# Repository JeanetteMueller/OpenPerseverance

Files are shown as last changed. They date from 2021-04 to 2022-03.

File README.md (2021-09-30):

# OpenPerseverance
This is a large Project about building your own Perseverance Mars Rover. 
3D printed and remote controlled. 

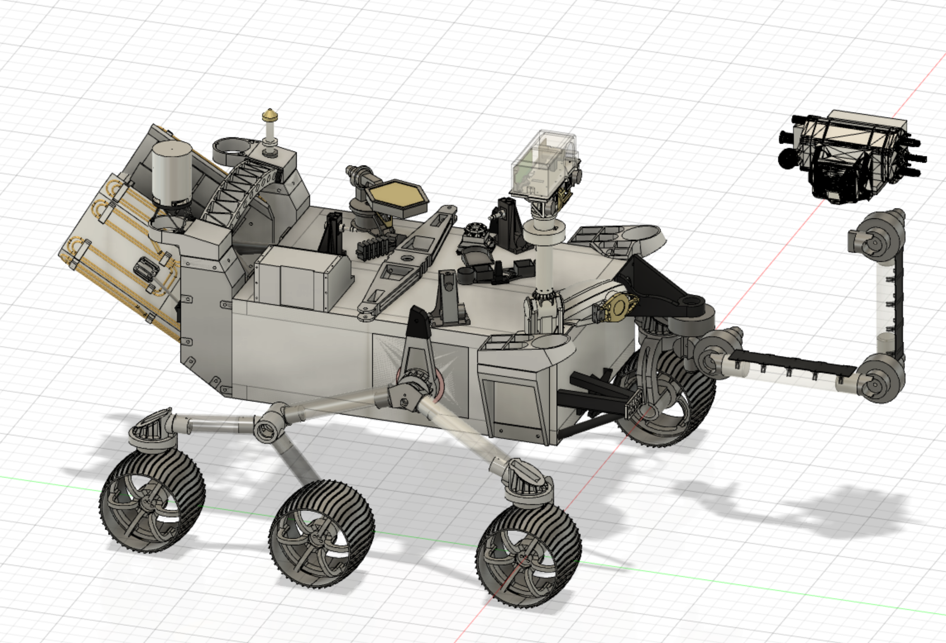
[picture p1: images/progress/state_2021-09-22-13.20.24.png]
CAD of Percy, 22. September 2021


Image of Percy with her Maker, 8. September 2021

Image of Percy, 8. September 2021

## Build your own rover
Under the Directory "stl" you find all needed printable parts for your rover. I will update and add new files while development.

### MainBody
* BridgeBase 
* DifferentialBodyMount
* DifferentialBlocker
* FrontBodyCamera
* HighGainAntenna
* LowGainAntenna
* SampleCollector
* ShellConnector
* ShellToProfileConnector
* SkyCraneConnector
* Sundial
* TopBox
* UHF

### RockerBogie
* WheelHolderCenter
* WheelHolder
* Tire
* Wheel Rim
* RodConnectorFront
* ServoConnector
* DifferentialMount
* RodConnectorBack
* DifferentialArm
* DifferentialArmHead
* CenterRodMount
* CenterRodMountCover
* BoogieCenterInternal
* BearingCenter
* BoogieCenterExternal
* BalanceArmConnector
* BalanceArmCenter
* BalanceArm

### Tower
(to be added)

### HeatExchanger
* Wall
* Holder
* Heatpipes
	
### Arm
(to be added)

## Remote Control
I designed everything to controll the rover with a PS4 Gamepad, connected to an iPhone. The iPhone is the brain of everything. It translate the gamepad signals to json code the rover need to move. The iPhone also shows the camera images of all installed cameras. 

## Rover brain
The Rover main Functions run on a Raspberry Pi 3b with 3 MotorController Boards and two Servo Shield. 
Inside of the Camera Tower you need a Raspberry Pi Zero W to control the Head mounted Camera and the Lights around the eyelid. 
All Programming is done in python (i am new with python so this would be a great opportunity to make this project better)

## Instructions

### Main Body
* 20x20 Alloy profile B-Type Nut 6
	4x 30cm
	5x 40cm
* 8x Angle 20 x 40 Nut 6 Bosch grid with fastening
* 50x Hammer Nut 6 M4
* Ball Bearings
	4x 35 x 47 x 7 mm   
	8x 8 x 22 x 7mm
* Alloy Rod 25 mm x 2 mm (inner Diameter 21mm)
	* 4x 150mm
	* 2x 100mm
	* 2x 120mm
* 4x JX Servo 1181MG
* 2x Servo MG90s
* Raspberry Pi 3b (or newer)
* Raspberry Pi Zero W
* Camera Longruner for Raspberry Pi
* ESP32 with Cam

### UHF Antenna
Needs 6 Carbon Rods: 40mm on front, 44mm on center and 41mm on the back. Two of each with a diameter of 2mm.

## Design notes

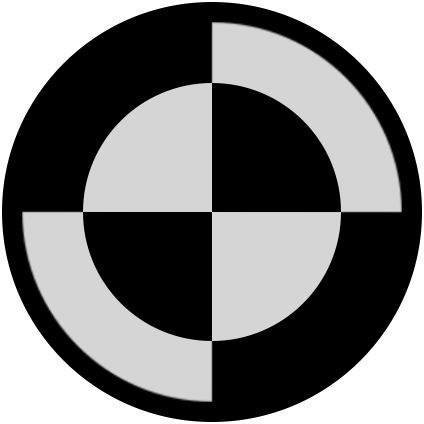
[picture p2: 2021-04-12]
images/decals/RoverMarker.png

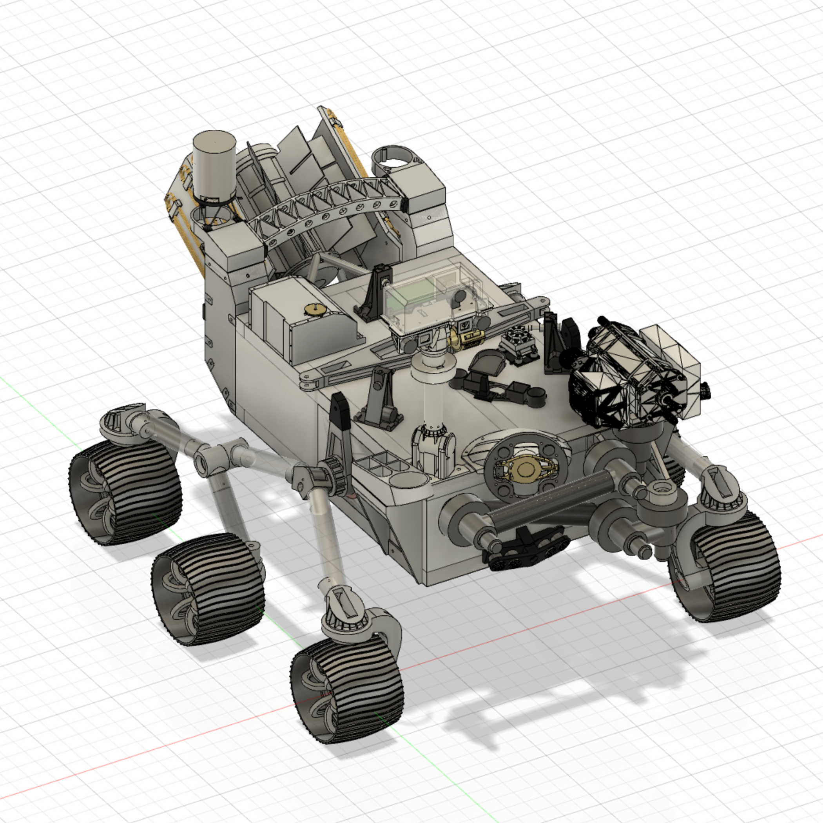
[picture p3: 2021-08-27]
images/progress/state_2021-08-19_17.00.37.png

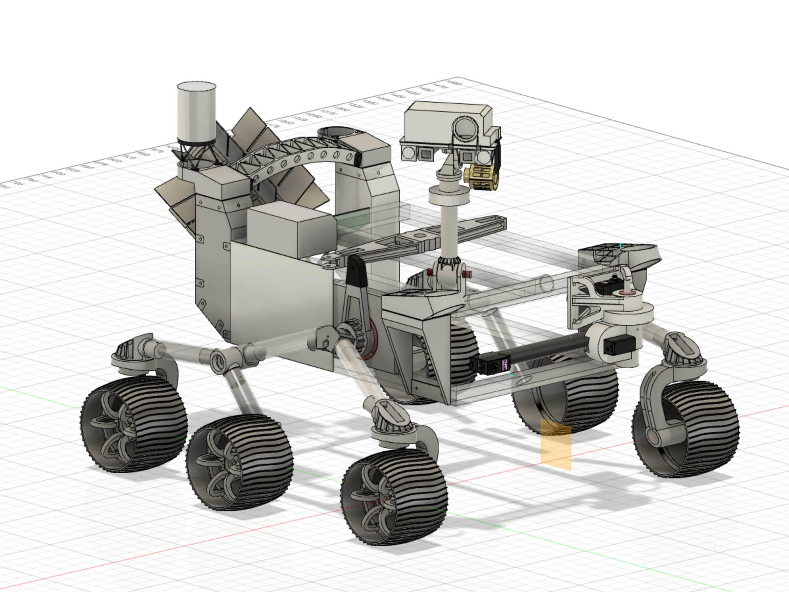
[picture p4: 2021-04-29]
images/progress/state_2021-04-29_10.36.57.png

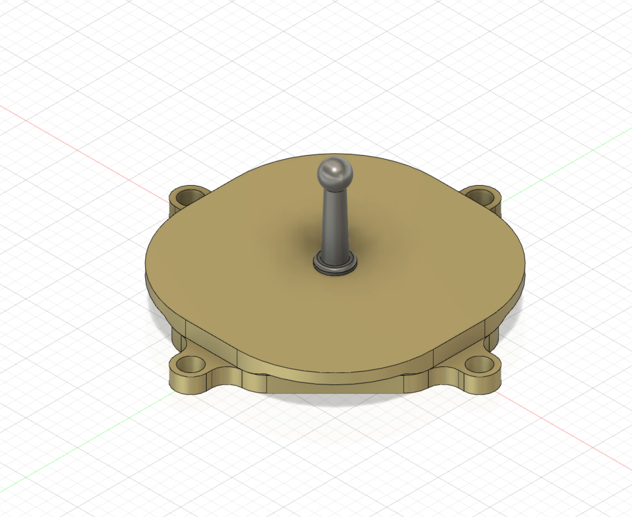
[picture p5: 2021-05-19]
stl/MainBody/Sundial/Sundial.png

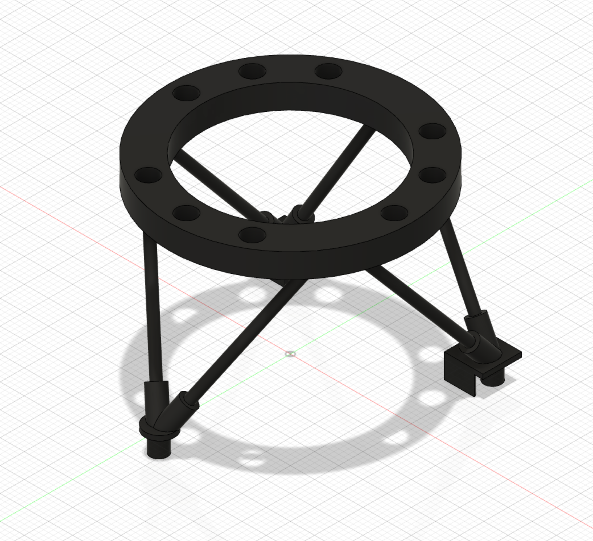
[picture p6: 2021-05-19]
stl/MainBody/UHF/UHF-Mount.png

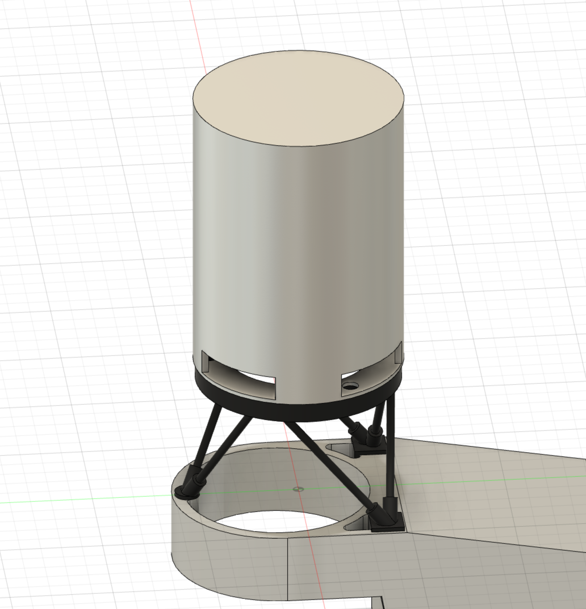
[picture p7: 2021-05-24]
stl/MainBody/UHF/UHF.png

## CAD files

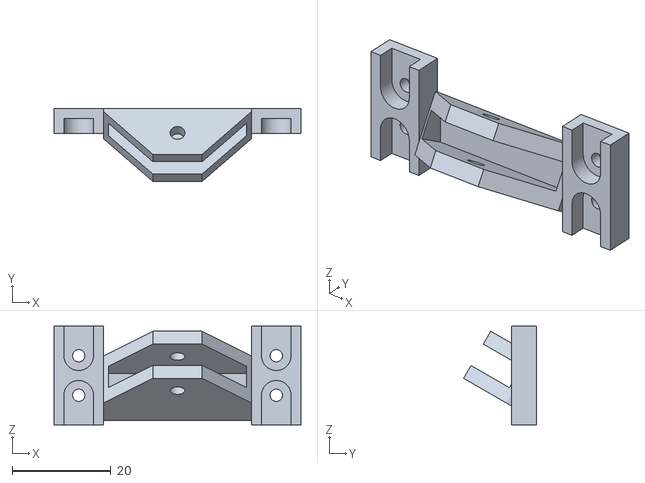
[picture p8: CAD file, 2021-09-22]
stl/HeatExchanger_Left/Holder/HeatExchangerHolder MainbodyMountPoint.stl
50.0 x 14.8 x 20.0

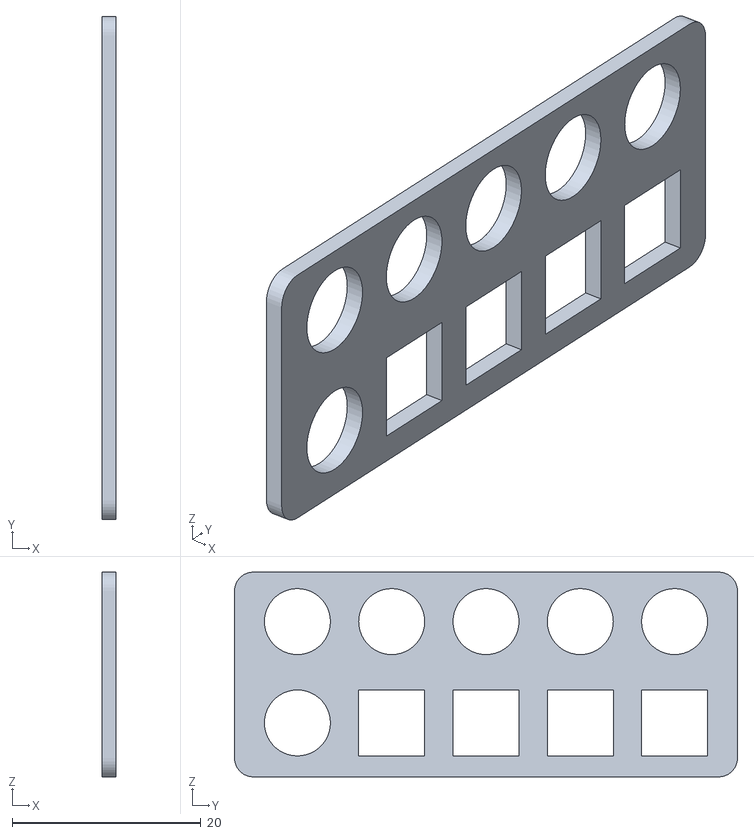
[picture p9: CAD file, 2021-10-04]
stl/Arm/ArmStandReferencesLid.stl
1.50 x 53.3 x 21.7

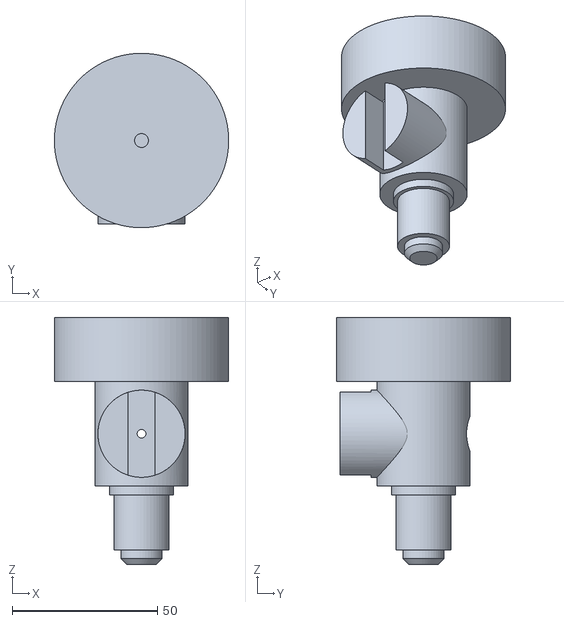
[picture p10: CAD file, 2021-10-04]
stl/Arm/Hand/HandActuator.stl
60.0 x 60.0 x 85.0

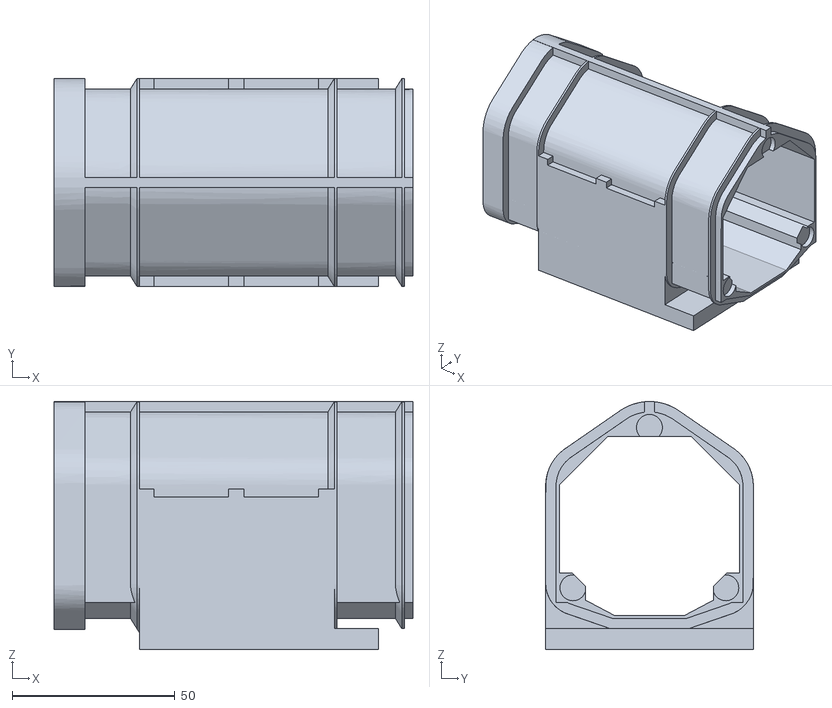
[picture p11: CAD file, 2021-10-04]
stl/Arm/Instruments/InstrumentsCenter.stl
110.4 x 63.9 x 76.3

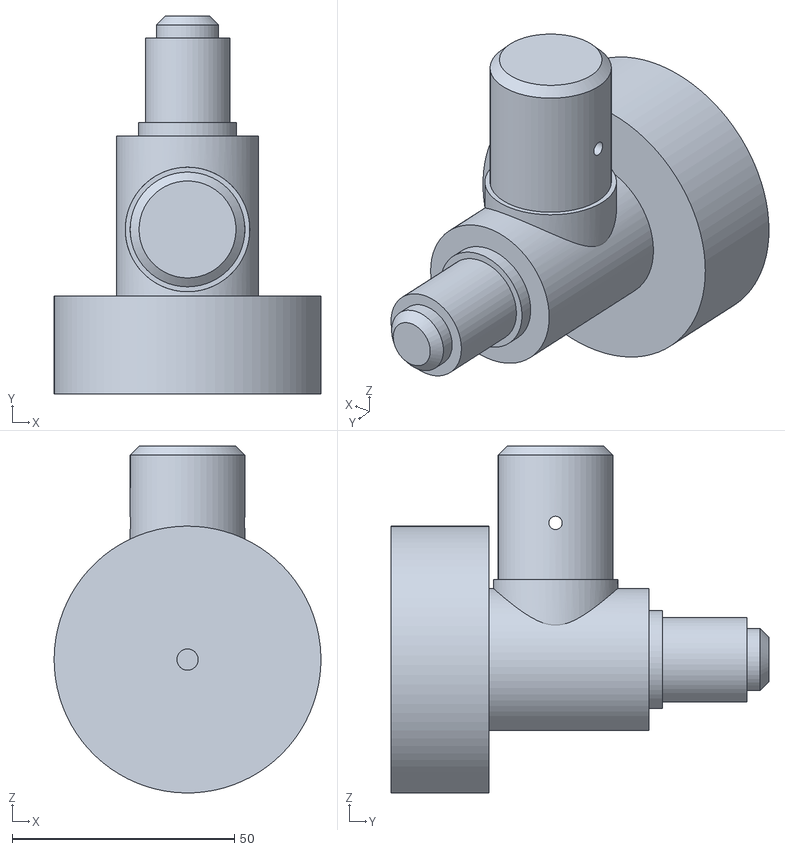
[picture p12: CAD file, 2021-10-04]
stl/Arm/LowerArm/LowerArmAktuator1.stl
60.0 x 85.0 x 78.0

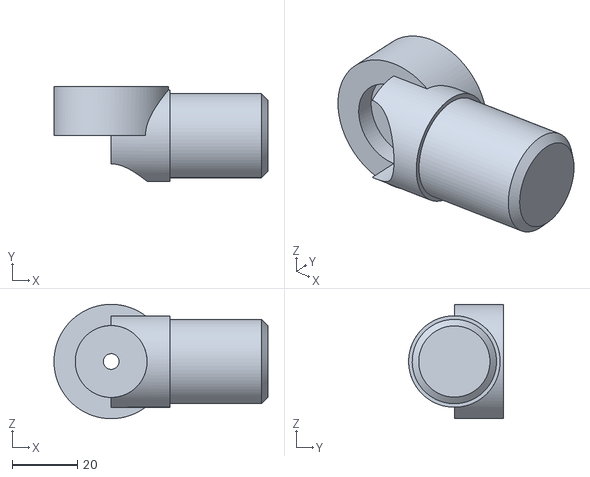
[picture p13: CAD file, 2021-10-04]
stl/Arm/UpperArm/UpperArmRodConnector1.stl
65.5 x 29.0 x 35.0

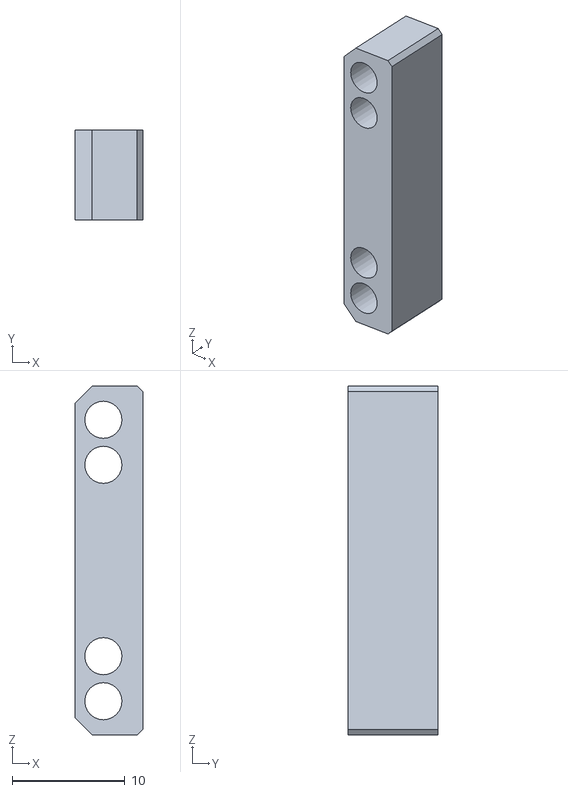
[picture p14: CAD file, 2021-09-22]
stl/HeatExchanger_Left/Heatpipes/HeatExchanger Holder 7.stl
6.00 x 8.00 x 31.0

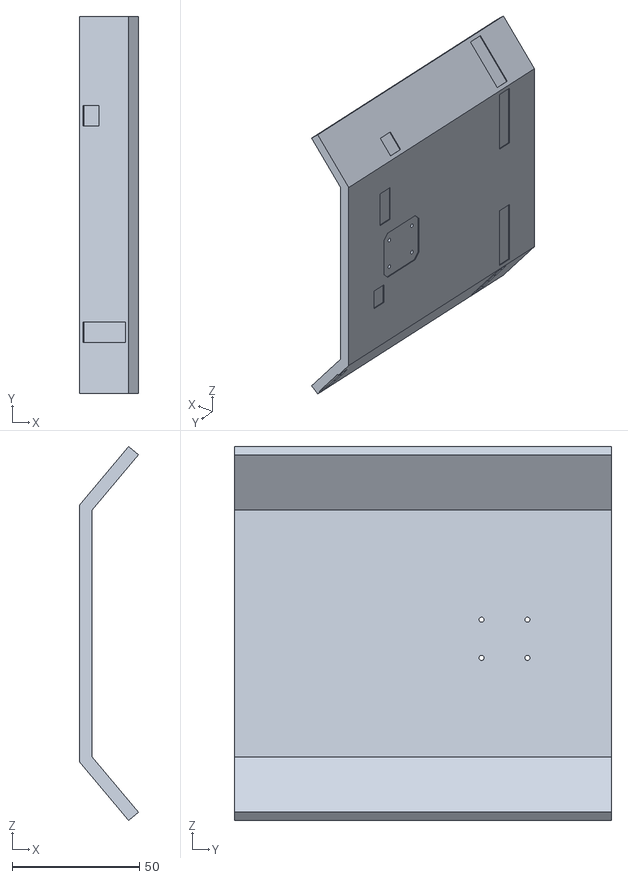
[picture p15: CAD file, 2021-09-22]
stl/HeatExchanger_Left/Wall/HeatExchanger Wall_Left_2.stl
23.2 x 148.0 x 146.8

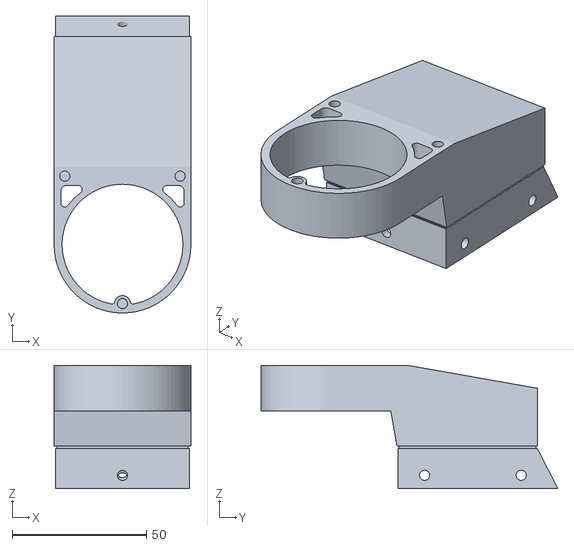
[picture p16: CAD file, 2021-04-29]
stl/MainBody/BridgeBase.stl
51.0 x 110.7 x 46.0

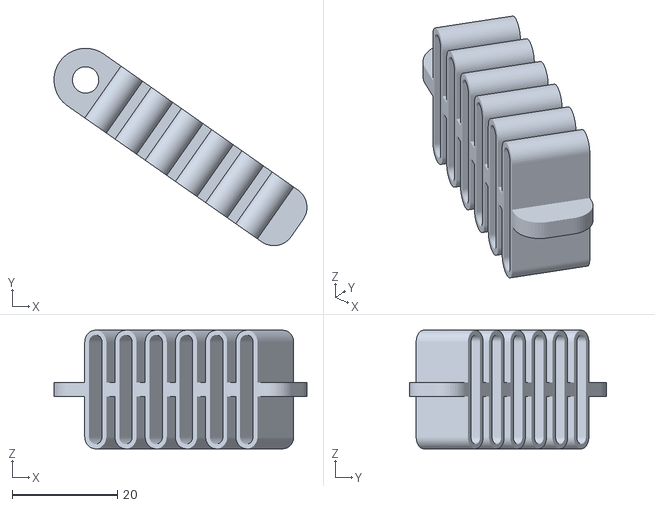
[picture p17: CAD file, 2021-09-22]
stl/MainBody/DifferentialBlocker/DifferentialBlocker Flex.stl
48.0 x 37.4 x 22.5

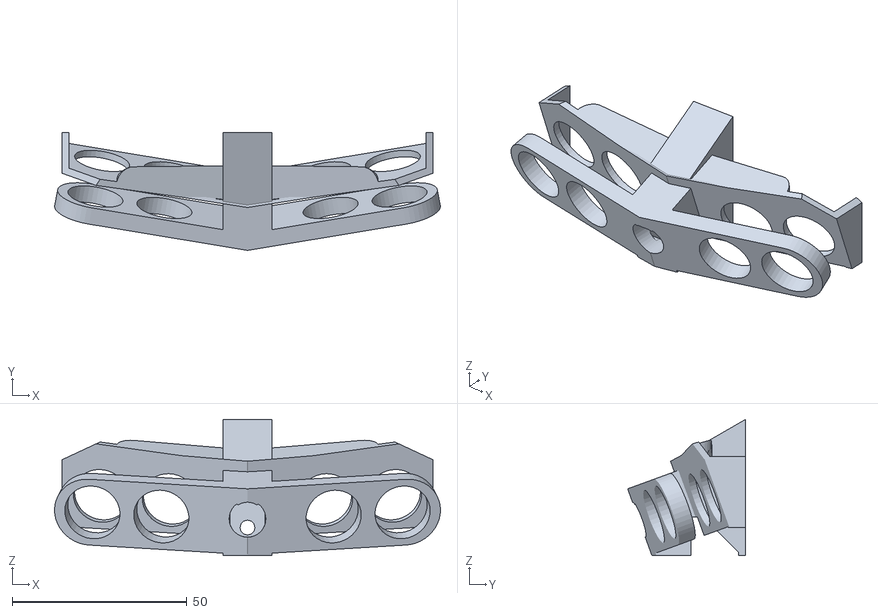
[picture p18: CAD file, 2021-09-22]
stl/MainBody/FrontBodyCamera/FrontBodyCameraHolder.stl
110.3 x 33.7 x 38.9

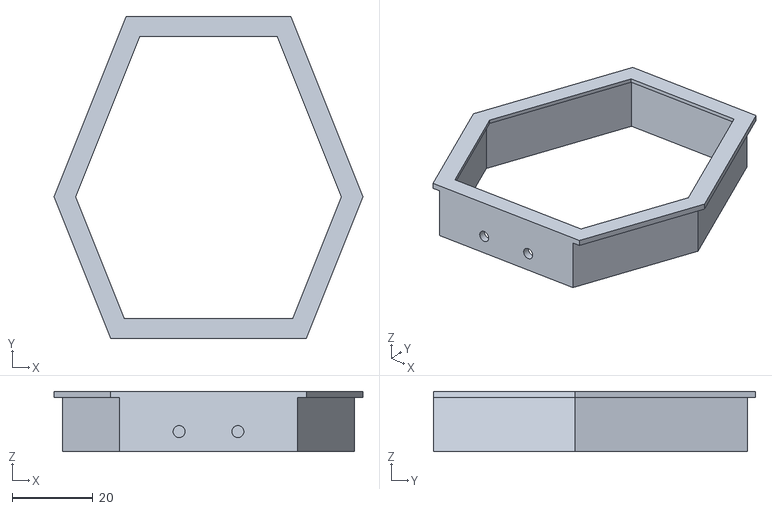
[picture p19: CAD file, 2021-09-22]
stl/MainBody/HighGainAntenna/HighGainAntenna RecieverCage.stl
76.8 x 80.0 x 15.0

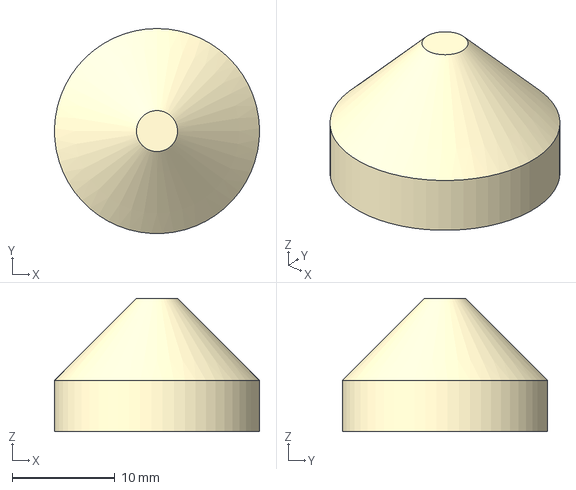
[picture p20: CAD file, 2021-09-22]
stl/MainBody/LowGainAntenna/LowGainAntenna Head.step
20.0 x 20.0 x 13.0 mm

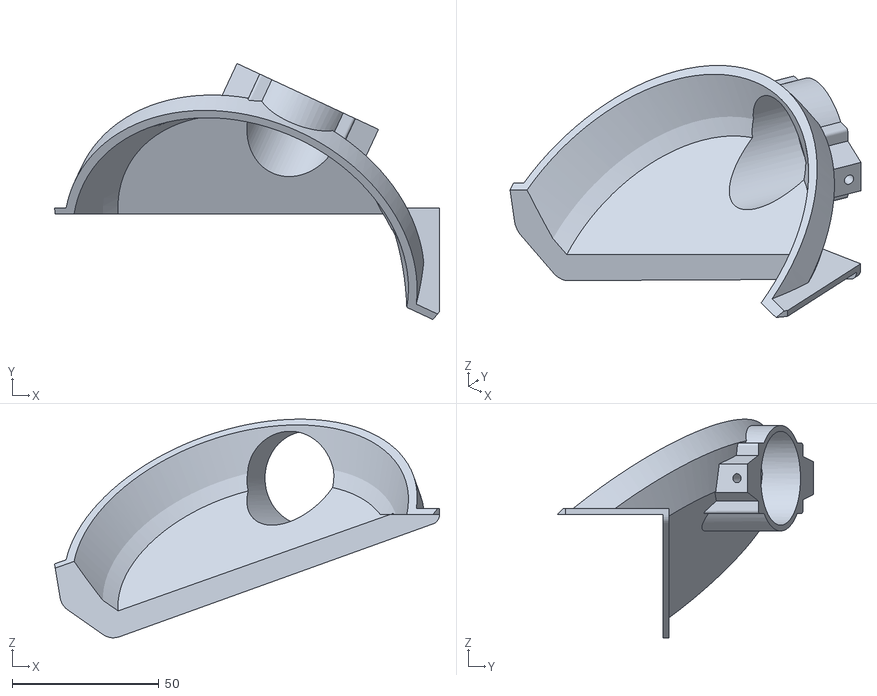
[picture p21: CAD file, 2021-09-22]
stl/MainBody/SampleCollector/CollectorBottom.stl
131.2 x 87.3 x 74.5

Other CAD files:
stl/MainBody/SkyCraneConnector/SkyCraneConnector CableCutter.stl
stl/MainBody/Sundial/SundialBase.stl
stl/MainBody/TopBox/TopBodyBox Back.stl
stl/MainBody/UHF/UHF-FootRight.stl
stl/Arm/ArmHolder.stl
stl/Arm/ArmStand.stl
stl/Arm/ArmStandReferencesMount.stl
stl/Arm/Hand/HandConnector.stl
stl/Arm/Instruments/InstrumentsBaseplate.stl
stl/Arm/Instruments/InstrumentsBaseplateConnector.stl
stl/Arm/Instruments/InstrumentsCamera.stl
stl/Arm/Instruments/InstrumentsCameraSensor.stl
stl/Arm/Instruments/InstrumentsDrill.stl
stl/Arm/Instruments/InstrumentsPixl.stl
stl/Arm/Instruments/InstrumentsSherlocWatsonBody.stl
stl/Arm/Instruments/InstrumentsSherlocWatsonSensor1.stl
stl/Arm/Instruments/InstrumentsSherlocWatsonSensor2.stl
stl/Arm/LowerArm/LowerArmAktuator2.stl
stl/Arm/NamePlate.stl
stl/Arm/NamePlateHolder.stl
stl/Arm/UpperArm/UpperArmAktuator2.stl
stl/Arm/UpperArm/UpperArmRodConnector2.stl
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

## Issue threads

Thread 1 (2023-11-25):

not enough detail

queenidog, 2023-11-25:
I don't see the detail (STL) around the connection between the drive motors and the wheel hub.  There are 3 screws holding the wheel on  but how is that connected to the motor shaft?   Where are the motors?

JeanetteMueller, 2023-11-27:
There is space for the motor in the "WheelHolder.stl". it should be a 27mm motor. There is space for the motor axle in the center. There are two additional holes to the left and right of this hole to securely fix the motor.

JeanetteMueller, 2023-11-27:
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

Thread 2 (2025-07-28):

Is the main body/frame structure missing?

Jstyund, 2025-07-28:
Hi,
I can’t find the main structural frame of the rover — like the chassis or base that holds everything together.
Is it missing, or just not included in the files? Or did I overlook it?

Thanks.

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

JeanetteMueller, 2025-07-28:
hi, these are just ABS plates i cuttet to the needed structure. it is not 3d printed.

JeanetteMueller, 2025-07-28:
the side plate goes up to the bridge, too.
i may have time later to take a photo and add measurements to it

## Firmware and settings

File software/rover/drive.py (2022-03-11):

#!/usr/bin/env python
from __future__ import division
from threading import Thread
import sys
import socket
import json
import time
from time import sleep
from Communication import Communication
from Communicator import Communicator

from adafruit_motorkit import MotorKit
import board

com = Communication("drive")

sock = com.getSocket()
sock.bind((com.ip, com.getPortForDrive()))

kit1 = MotorKit(address=0x62)
kit2 = MotorKit(address=0x61)

class DriveReactor(Thread):
    changed = 1
    timeout = 0
    motorLeft = 0
    motorLeftCenter = 0
    
    motorRight = 0
    motorRightCenter = 0
    
    def __init__(self):
        Thread.__init__(self)
        self.daemon = True
        self.start()

    def run(self):
        print("start run")
        while True:
            if self.timeout > 0:
                self.timeout = self.timeout - 1

            if self.timeout <= 0:
                self.motorLeft = 0
                self.motorLeftCenter = 0
                self.motorRight = 0
                self.motorRightCenter = 0
                print("-------------- FULL STOP -------------")

            kit1.motor1.throttle = self.motorLeft
            kit1.motor3.throttle = self.motorLeft
            kit1.motor2.throttle = self.motorLeftCenter
            kit2.motor1.throttle = self.motorRight
            kit2.motor3.throttle = self.motorRight
            kit2.motor2.throttle = self.motorRightCenter
            print("set new motor values " + str(self.timeout))
            sleep(0.02)
            
    def newTimeout(self):
        self.timeout = 10
        print("--------------------set new timeout ")
    def parseMessage(self,msg):
        jsonData = json.loads(msg)
        print("parse message for drive " + str(msg))
        
        if "drive" in jsonData:
            drive = jsonData["drive"]

            self.newTimeout()
            if "ml" in drive:
                if "mlc" in drive:
                    if "mr" in drive:
                        if "mrc" in drive:
                            self.motorLeft = drive["ml"]
                            self.motorLeftCenter = drive["mlc"]
                            self.motorRight = drive["mr"] * -1
                            self.motorRightCenter = drive["mrc"] * -1
                            

runner = DriveReactor()
Communicator(sock, runner)

while True:
    #print("main while loop")
    pass

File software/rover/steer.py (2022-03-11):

#!/usr/bin/env python
from __future__ import division

from threading import Thread
import sys
import socket
import json
import time
import math
from time import sleep

# from PCA9685 import PCA9685
from Adafruit_PCA9685 import PCA9685

from Communication import Communication
from Communicator import Communicator
from Helper import Helper

com = Communication("steer")

sock = com.getSocket()
sock.bind((com.ip, com.getPortForSteer()))

#### Servo
pwm = PCA9685(address=0x40)
servo_min = 150.0  # Min pulse length out of 4096
servo_max = 650.0  # Max pulse length out of 4096
pwm.set_pwm_freq(50)

class SteerReactor(Thread):
    helper = Helper()
    
    lastSteerChange = 0
    lastArmChange = 0
    
    steerFrontLeft  = 85
    steerFrontRight = 85
    steerBackLeft   = 85
    steerBackRight  = 85
    
    steerChanged = 0
    
    armJoint1 = 85
    armJoint2 = 85
    armJoint3 = 85
    armJoint4 = 85
    
    armChanged = 0
    
    def __init__(self):
        Thread.__init__(self)
        self.daemon = True
        self.start()

    def run(self):
        while True:
            if self.steerChanged == 1:
                pwm.set_pwm(0, 0, int(self.helper.getPulseFromAngle(self.steerFrontLeft, servo_min, servo_max)))
                pwm.set_pwm(1, 0, int(self.helper.getPulseFromAngle(self.steerFrontRight, servo_min, servo_max)))
                pwm.set_pwm(2, 0, int(self.helper.getPulseFromAngle(self.steerBackLeft, servo_min, servo_max)))
                pwm.set_pwm(3, 0, int(self.helper.getPulseFromAngle(self.steerBackRight, servo_min, servo_max)))
                self.steerChanged = 0
                
            if self.armChanged == 1:
                pwm.set_pwm(12, 0, int(self.helper.getPulseFromAngle(self.armJoint1, 150, 650)))
                self.armChanged = 0
            
            sleep(0.001)

    def parseMessage(self,msg):
        jsonData = json.loads(msg)
        
        if "steer" in jsonData:
            steer = jsonData["steer"]
            if "time" in steer:
                if steer["time"] > self.lastSteerChange:
                    if "fl" in steer:
                        if "fr" in steer:
                            if "bl" in steer:
                                if "br" in steer:
                                    print("set new steer data " + str(msg))
                                    self.steerFrontLeft = steer["fl"]
                                    self.steerFrontRight = steer["fr"]
                                    self.steerBackLeft = steer["bl"]
                                    self.steerBackRight = steer["br"]
                                    self.lastSteerChange = steer["time"]
                                    self.steerChanged = 1
        if "arm" in jsonData:
            arm = jsonData["arm"]
            if "time" in arm:
                if arm["time"] > self.lastArmChange:
                    if "j1" in arm:
                        if "j2" in arm:
                            if "j3" in arm:
                                if "j4" in arm:
                                    self.armJoint1 = arm["j1"]
                                    self.armJoint2 = arm["j2"]
                                    self.armJoint3 = arm["j3"]
                                    self.armJoint4 = arm["j4"]
                                    self.lastArmChange = arm["time"]
                                    self.armChanged = 1
                            
                            

runner = SteerReactor()
Communicator(sock, runner)

while True:
    pass

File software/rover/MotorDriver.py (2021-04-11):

MotorDriverDirection = [
    'forward',
    'backward',
]


class MotorDriver():
    def __init__(self):
        self.PWMA = 0
        self.AIN1 = 1
        self.AIN2 = 2
        self.PWMB = 5
        self.BIN1 = 3
        self.BIN2 = 4

    def MotorRun(self, pwm, motor, index, speed):
        if speed > 100:
            return
        if(motor == 0):
            pwm.setDutycycle(self.PWMA, speed)
            if(index == MotorDriverDirection[0]):
                pwm.setLevel(self.AIN1, 0)
                pwm.setLevel(self.AIN2, 1)
            else:
                pwm.setLevel(self.AIN1, 1)
                pwm.setLevel(self.AIN2, 0)
        else:
            pwm.setDutycycle(self.PWMB, speed)
            if(index == MotorDriverDirection[0]):
                pwm.setLevel(self.BIN1, 0)
                pwm.setLevel(self.BIN2, 1)
            else:
                pwm.setLevel(self.BIN1, 1)
                pwm.setLevel(self.BIN2, 0)

    def MotorStop(self, pwm, motor):
        if (motor == 0):
            pwm.setDutycycle(self.PWMA, 0)
        else:
            pwm.setDutycycle(self.PWMB, 0)

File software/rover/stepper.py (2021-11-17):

import RPi.GPIO as GPIO
import time
from DRV8825 import DRV8825



Motor1 = DRV8825(dir_pin=13, step_pin=19, enable_pin=12, mode_pins=(16 , 17, 20))
Motor2 = DRV8825(dir_pin=24, step_pin=18, enable_pin=4, mode_pins=(21, 22, 27))

"""
# 1.8 degree: nema23, nema14
# softward Control :
# 'fullstep': A cycle = 200 steps
# 'halfstep': A cycle = 200 * 2 steps
# '1/4step': A cycle = 200 * 4 steps
# '1/8step': A cycle = 200 * 8 steps
# '1/16step': A cycle = 200 * 16 steps
# '1/32step': A cycle = 200 * 32 steps
"""

#s = 200 * 32
#delay = 1.0 / s # 0.0005

#Motor1.TurnStep(Dir='forward', steps=s, stepdelay=delay)
#time.sleep(1.0)

#Motor1.TurnStep(Dir='backward', steps=s, stepdelay=delay)
#time.sleep(1.0)

#Motor2.TurnStep(Dir='forward', steps=s, stepdelay=delay)
#time.sleep(1.0)

#Motor2.TurnStep(Dir='backward', steps=s, stepdelay=delay)


#Motor1.Stop()
#Motor2.Stop()


def rotateBy(motor, deg, duration):

    dir = 'forward'
    if (deg < 0):
        dir = 'backward'
        deg = deg * -1
    s = 6406.0 / 16 / 360.0 * deg

    delay = 0
    if (duration > 0):
    	delay = duration / s

    #motor.SetMicroStep('software', 'halfstep')
    motor.TurnStep(Dir=dir, steps=int(s), stepdelay=delay)
    motor.Stop()

#rotateBy(Motor1, 90, 0.5)

rotateBy(Motor2, 90, 0.5)

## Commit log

2021-04-12 rocker boogie and main body files
    [BalanceArmCenter_v2.stl, BalanceArmConnector_v1.stl, BalanceArm_v2.stl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]
2021-04-15 To drive, you need wheels. Now you have them!
    Print Tire with 92A TPU
    [Wheel Rim v14.stl, WheelHolder v2.stl, WheelHolderCenter v2.stl]
2021-04-22 New overview about rover status. now steering change motor rotation to match the circles to drive
2021-04-25 Neu CAD Image, driving fixed for new motors
    [drive.py]
2021-04-27 swap ui elements on the ios remote app, controling the instruments arm now with the dPad while constructing.
2021-04-29 New CAD Image, Extra Information about the UHF Antenna. UHF Antenna Stand Files, Bridge Holder and Shell Connectors
    [BridgeBase.stl, ShellConnector.stl, ShellToProfileConnector.stl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]
2021-05-07 remote app updated, power service merged to information service. some stl files
    [FrontBodyCamera.stl, FrontBodyCameraHolder.stl]
2021-05-12 New Services und updates for second raspberry inside of the tower
2021-05-15 fix on ui and sound is now playable
    [sound.py]
2021-05-19 New Sundial, extra Image of UHF
    [FrontBodyCamera.stl, FrontBodyCameraHolder.stl, SundialBase.stl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]
2021-05-24 This Cover hides the big screws.
    [DifferentialStaticCover.stl]
2021-05-24 Center Rod Mount Update. Old one broke!
    [CenterRodMount.stl, CenterRodMountCover.stl, CenterRodMount_v7.stl]
2021-06-19 LaserPointer Controll added
2021-06-20 New sample collector with openable closure
    [CollectorBottom.stl, CollectorTop.stl, Hatch.stl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]
2021-06-23 updated Sundial, slower tower rotation
    [SundialBase.stl, SundialPin.stl]
2021-06-24 Better COntrol over the Tower tilt, new AppIcon, Save Photos from Camera View directly to the Camera Roll
2021-08-27 large updates of the 3d printed rover, arm, skycrane mountpoints
2021-09-22 Differential Blocker for Rocker Boogie
    [DifferentialBlocker Base.stl, DifferentialBlocker Flex.stl]
2021-09-22 LowGain Antenna
    [LowGainAntenna Foot.stl, LowGainAntenna Head.step, LowGainAntenna Mount.stl]
2021-09-22 Multi Part High Gain Antenna
    [HighGainAntenna Base.stl, HighGainAntenna Holder.step, HighGainAntenna RecieverCage.stl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]
2021-09-22 fixed stl export
    [CollectorBottom.stl]
2021-09-22 export without cameras. separat files available
    [FrontBodyCameraHolder.stl]
2021-09-22 Sky Crane Connector Parts
    [SkyCraneConnector Base.stl, SkyCraneConnector CableCutter.stl]
2021-09-22 Top Body Box
    [TopBodyBox Back.stl, TopBodyBox Front.stl]
2021-09-22 Heat Exchanger System
    [HeatExchanger Holder 1.stl, HeatExchanger Holder 2.stl, HeatExchanger Holder 3.stl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]
2021-09-22 Update of the current state
2021-09-27 Updated interface. remove of third camera, ui fixes. blue button. versioninfo
2021-10-04 Instruments Arm Base and Stand with References Panel for SuperCam
    [ArmHolder.stl, ArmStand.stl, ArmStandReferencesLid.stl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]
2021-10-04 Arm Parts
    [HandActuator.stl, HandConnector.stl, InstrumentsBaseplate.stl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]
2021-10-13 Drill hole of BoogieCenterExternal fixed. Files renamed
    [BalanceArm.stl, BalanceArmCenter.stl, BalanceArmConnector.stl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]
2021-10-26 New Settings page to calibrate the steering servos
2021-11-16 new multi threaded communication and better use of the 3 colors on the camera tower. a lot optimizations
2021-11-17 better driving and steering
2022-03-11 savety update for driving when no new signal incoming; some new stl files
    [BalanceArm.stl, BalanceArmBlockerHead.stl, BalanceArmCenter.stl]
2024-09-03 phone app update with just one camera and lights removed
2024-09-03 updated motor mounts
    [CenterRodMount_v2.stl, DifferentialMount_v2.stl, WheelAdapter.stl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]
